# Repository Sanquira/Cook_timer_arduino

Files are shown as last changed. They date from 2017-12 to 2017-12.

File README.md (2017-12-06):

# Cook_timer_arduino

Project of Cooking timer based on Arduino Nano ATmega328.

Project is designed with focus on modularity. Therefore there are few independent modules:

Event       - Simple event template. Used for firing events like button pressed, buzzer melody ended (or was ended),
              timer timed out.

Button      - Module which allows you to register button on pin with debounce feature and event response in program.

Buzzer      - Module for sound output with support of melody and/or cycle play.

TimerLogic  - Module for time measure designed on minutes scale. Fire event when timer ends.
              Inner timer count in millis. There is support for "live" add/remove time.
              It will return you remaining time in minutes and in seconds and second ticking indicator.
              Timer reset itself when stopped.

LedDisp     - Module for 4 digits 7-segments LED display. It uses multiplex technology so it needs 8 + 4 pins when registering.

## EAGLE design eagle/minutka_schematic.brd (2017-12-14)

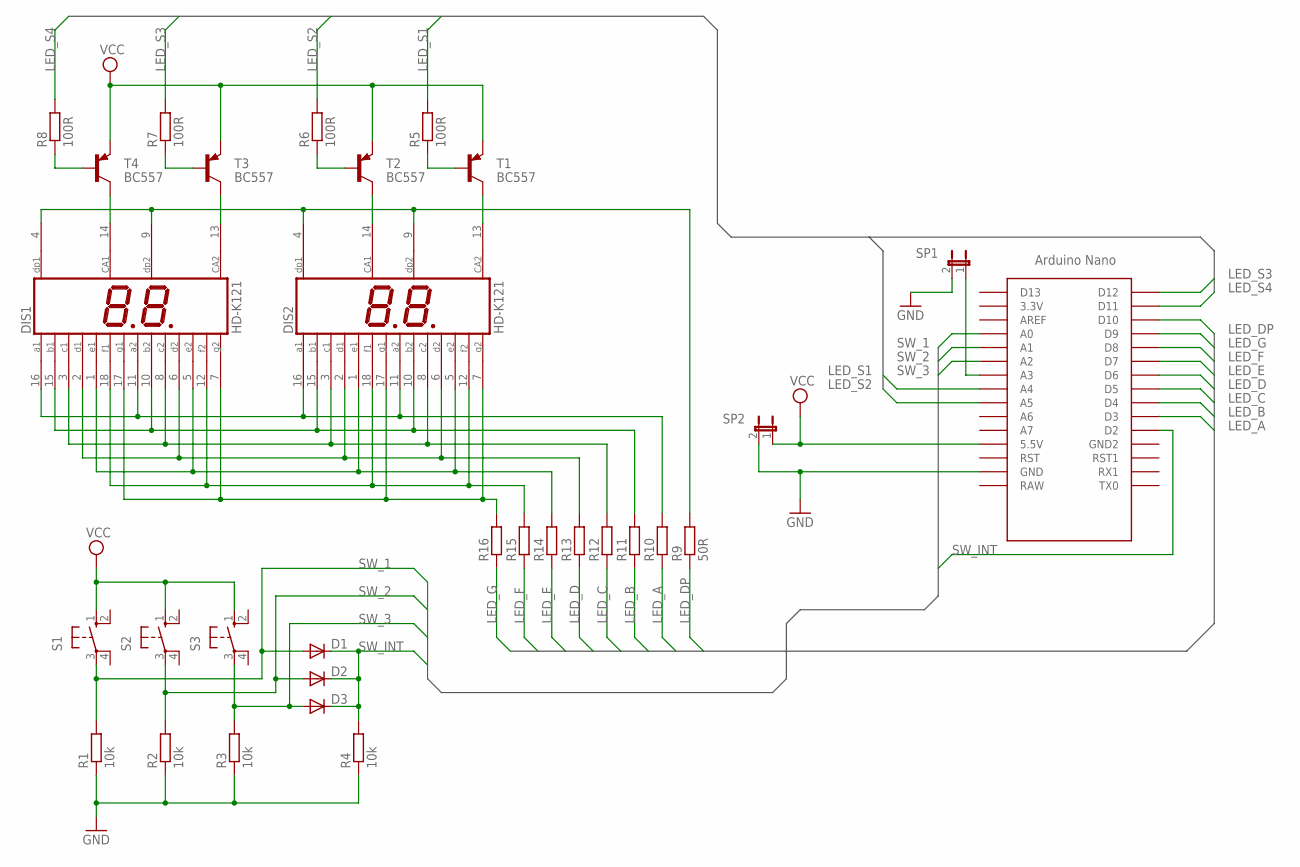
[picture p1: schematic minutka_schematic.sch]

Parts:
D1, D2, D3: DIODE-D-5; D-5
DIS1, DIS2: HD-K121; HDSP-R
R1, R2, R3, R4: 10k; 0204/7
R5, R6, R7, R8: 100R; 0204/7
R9: 50R; 0204/7
R10, R11, R12, R13, R14, R15, R16: R-EU_0204/7; 0204/7
S1, S2, S3: 10-XX; B3F-10XX
SP1, SP2: JP1E; JP1
T1, T2, T3, T4: BC557; TO92-EBC
U$1: NANO

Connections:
GND: R1.1, R2.1, R3.1, R4.1, SP1.2, SP2.2, U$1.GND
LED_A: R10.1, U$1.D3
LED_B: R11.1, U$1.D4
LED_C: R12.1, U$1.D5
LED_D: R13.1, U$1.D6
LED_DP: R9.1, U$1.D10
LED_E: R14.1, U$1.D7
LED_F: R15.1, U$1.D8
LED_G: R16.1, U$1.D9
LED_S1: R5.2, U$1.A4
LED_S2: R6.2, U$1.A5
LED_S3: R7.2, U$1.D12
LED_S4: R8.2, U$1.D11
unnamed: DIS1.11 (A2), DIS1.16 (A1), DIS2.11 (A2), DIS2.16 (A1), R10.2
unnamed: DIS1.10 (B2), DIS1.15 (B1), DIS2.10 (B2), DIS2.15 (B1), R11.2
unnamed: DIS1.3 (C1), DIS1.8 (C2), DIS2.3 (C1), DIS2.8 (C2), R12.2
unnamed: DIS1.2 (D1), DIS1.6 (D2), DIS2.2 (D1), DIS2.6 (D2), R13.2
unnamed: DIS1.1 (E1), DIS1.5 (E2), DIS2.1 (E1), DIS2.5 (E2), R14.2
unnamed: DIS1.12 (F2), DIS1.18 (F1), DIS2.12 (F2), DIS2.18 (F1), R15.2
unnamed: DIS1.7 (G2), DIS1.17 (G1), DIS2.7 (G2), DIS2.17 (G1), R16.2
unnamed: DIS1.4 (DP1), DIS1.9 (DP2), DIS2.4 (DP1), DIS2.9 (DP2), R9.2
unnamed: DIS2.13 (CA2), T1.C
unnamed: DIS2.14 (CA1), T2.C
unnamed: DIS1.13 (CA2), T3.C
unnamed: DIS1.14 (CA1), T4.C
unnamed: R7.1, T3.B
unnamed: R8.1, T4.B
unnamed: R6.1, T2.B
unnamed: R5.1, T1.B
unnamed: SP1.1, U$1.A3
SW_1: D1.A, R1.2, S1.3, U$1.A0
SW_2: D2.A, R2.2, S2.3, U$1.A1
SW_3: D3.A, R3.2, S3.3, U$1.A2
SW_INT: D1.C, D2.C, D3.C, R4.2, U$1.D2
VCC: S1.1 (S), S2.1 (S), S3.1 (S), SP2.1, T1.E, T2.E, T3.E, T4.E, U$1.5V (5.5V)

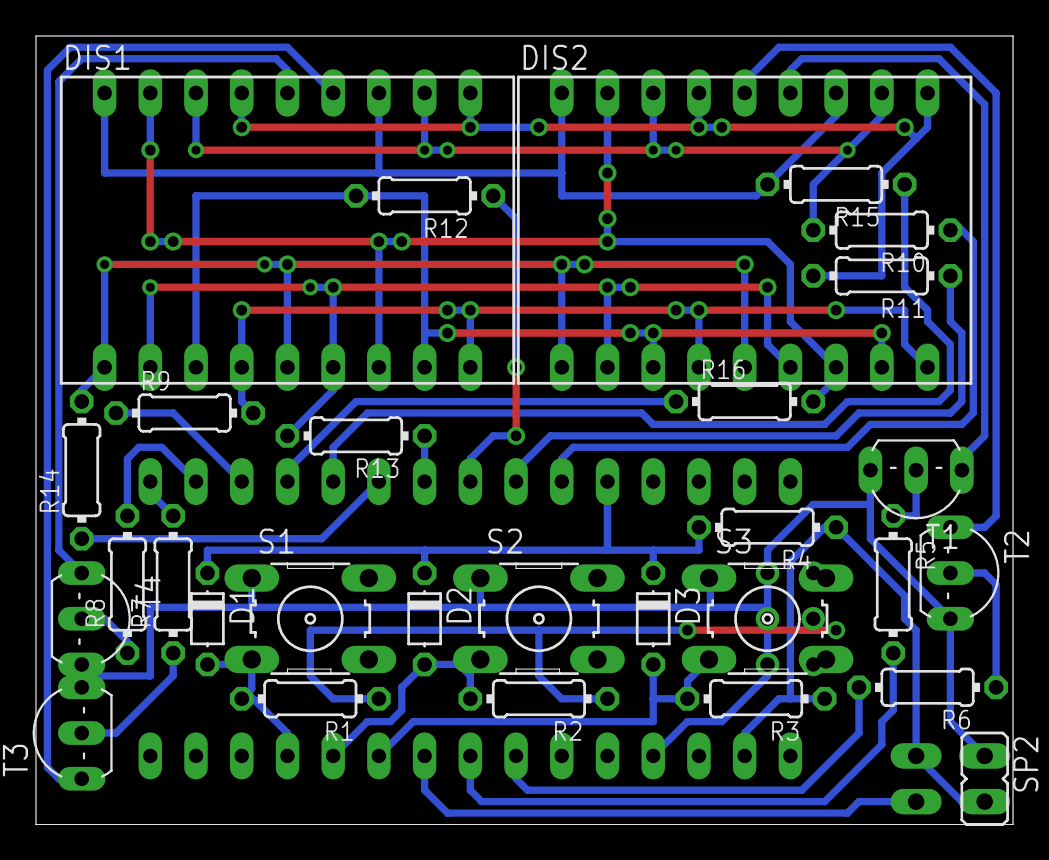
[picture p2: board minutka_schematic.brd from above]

Board: 2 copper layers, 54.3 x 43.8 mm, 31 parts (1 on the bottom side), 35 nets.

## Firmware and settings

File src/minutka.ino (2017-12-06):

#include "LedDisp.h"
#include "Button.h"
#include "TimerLogic.h"
#include "Buzzer.h"
#include <avr/sleep.h>

void wakeUpNow();

bool m_isWakingUp;
LedDisp led;
Buzzer buzzer = Buzzer(4);
TimerLogic timer;
TimerLogic sleepTimer;
class timers {
  public:
    void timers::init() {
      timer.setTimeoutEvent(new EventHandler<timers, TimeoutEventArgs>(this, &timers::onTimeout));
      sleepTimer.setTimeoutEvent(new EventHandler<timers, TimeoutEventArgs>(this, &timers::onSleepTimeout));
      sleepTimer.setDesiredTime(10000);
    }

    void timers::onTimeout(TimeoutEventArgs* args) {
      buzzer.startBuzzer();
      sleepTimer.stopTimer();
    }

    void timers::onSleepTimeout(TimeoutEventArgs* args) {
      led.setEnabled(false);
      sleep_enable();
      attachInterrupt(digitalPinToInterrupt(2), wakeUpNow, HIGH);
      sleep_mode();
      // THE PROGRAM CONTINUES FROM HERE AFTER WAKING UP
      sleep_disable();
      detachInterrupt(digitalPinToInterrupt(2));
      led.setEnabled(true);
    }

    void timers::onStupidTimeout(TimeoutEventArgs* args) {
      timer.startTimer();
      sleepTimer.stopTimer();
    }

    void timers::process(unsigned long currentMillis) {
      timer.process(currentMillis);
      sleepTimer.process(currentMillis);
    }

} timers;
class Buttons {
  public:
    Button startButton, plusButton, minusButton;

    void Buttons::init() {
      plusButton.registerButton(A0, new EventHandler<Buttons, ButtonEventArgs>(this, &Buttons::onPlusPressed));
      startButton.registerButton(A2, new EventHandler<Buttons, ButtonEventArgs>(this, &Buttons::onStartPressed));
      minusButton.registerButton(A1, new EventHandler<Buttons, ButtonEventArgs>(this, &Buttons::onMinusPressed));
    }

    void Buttons::onPlusPressed(ButtonEventArgs* args) {
      if (m_isWakingUp) {
        m_isWakingUp = false;
        sleepTimer.resetTimer();
        return;
      }
      timer.increaseTime();
      if (!timer.isRunning())
        sleepTimer.resetTimer();
    }

    void Buttons::onMinusPressed(ButtonEventArgs* args) {
      if (m_isWakingUp) {
        m_isWakingUp = false;
        sleepTimer.resetTimer();
        return;
      }
      timer.decreaseTime();
      if (!timer.isRunning())
        sleepTimer.resetTimer();
    }

    void Buttons::onStartPressed(ButtonEventArgs* args) {
      if (m_isWakingUp) {
        m_isWakingUp = false;
        sleepTimer.resetTimer();
        return;
      }
      if (buzzer.isRunning()) {
        buzzer.stopBuzzer();
        sleepTimer.resetTimer();
        return;
      }
      if (timer.isRunning()) {
        timer.stopTimer();
        sleepTimer.resetTimer();
      }
      else {
        timer.startTimer();
        sleepTimer.stopTimer();
      }
    }

    void process(unsigned long currentMillis) {
      plusButton.process(currentMillis);
      startButton.process(currentMillis);
      minusButton.process(currentMillis);
    }

} buttons;
class Buzzers {
  public:
    void Buzzers::init() {
      buzzer.registerBuzzer(A3, new EventHandler<Buzzers, BuzzerEventArgs>(this, &Buzzers::onEnded), true);
      // fur elise 20
      //      buzzer.addTone(NOTE_E6, 250);
      //      buzzer.addTone(NOTE_DS6, 250);
      //      buzzer.addTone(NOTE_E6, 250);
      //      buzzer.addTone(NOTE_DS6, 250);
      //      buzzer.addTone(NOTE_E6, 250);
      //      buzzer.addTone(NOTE_B5, 250);
      //      buzzer.addTone(NOTE_D6, 250);
      //      buzzer.addTone(NOTE_C6, 250);
      //      buzzer.addTone(NOTE_A5, 250);
      //      buzzer.addTone(0, 50);
      //      buzzer.addTone(NOTE_C5, 250);
      //      buzzer.addTone(NOTE_E5, 250);
      //      buzzer.addTone(NOTE_A5, 250);
      //      buzzer.addTone(NOTE_B5, 250);
      //      buzzer.addTone(0, 50);
      //      buzzer.addTone(NOTE_E5, 250);
      //      buzzer.addTone(NOTE_GS5, 250);
      //      buzzer.addTone(NOTE_B5, 250);
      //      buzzer.addTone(NOTE_C6, 250);
      //      buzzer.addTone(0, 50);
      // annoying 4
      buzzer.addTone(1600, 500);
      buzzer.addTone(1500, 500);
      buzzer.addTone(1400, 500);
      buzzer.addTone(1500, 500);
    }

    void Buzzers::onEnded(BuzzerEventArgs* args) {
      sleepTimer.resetTimer();
      led.dispDP2(1);
    }
} buzzers;

void setup() {
  int arr[] = {3, 4, 5, 6, 7, 8, 9, 10};
  led.init(arr, 11, 12, A5, A4);
  buttons.init();
  timers.init();
  buzzers.init();

  led.dispDP2(1);

  set_sleep_mode(SLEEP_MODE_PWR_DOWN);
  m_isWakingUp = false;
  sleepTimer.startTimer();
}

void loop() {
  unsigned long currentMillis = millis();
  timers.process(currentMillis);
  led.dispNumber(timer.getDisplayTimeMinutes(), timer.getDisplayTimeSeconds());
  led.dispDP2(timer.getSecondMark());
  led.draw(currentMillis);
  buttons.process(currentMillis);
  buzzer.process(currentMillis);
}

void wakeUpNow()
{
  m_isWakingUp = true;
  // execute code here after wake-up before returning to the loop() function
  // timers and code using timers (serial.print and more...) will not work here.
}

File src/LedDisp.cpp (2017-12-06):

#include "LedDisp.h"

LedDisp::LedDisp() {}

LedDisp::~LedDisp() {
  delete [] arr;
}

void LedDisp::init(int segmsLed[8], int minuteD, int minuteU, int secondD, int secondU) {
  for (int i = 0; i < 8; i++) {
    arr[i] = segmsLed[i];
  }
  drawPins[0] = minuteD;
  drawPins[1] = minuteU;
  drawPins[2] = secondD;
  drawPins[3] = secondU;

  currentDraw = 0;
  for (int i = 0; i < 8; i++) {
    pinMode(arr[i], OUTPUT);
    pinMode(arr[i], LED_RST);
  }
  for (int i = 0; i < 4; i++) {
    pinMode(drawPins[i], OUTPUT);
  }
  enableDigits(false);
  setEnabled(true);
}

void LedDisp::draw(unsigned long currentMillis) {
  if (!m_enabled)return;
  if (currentMillis - previousDraw_ms >= DRAW_INTERVAL) {
    previousDraw_ms = currentMillis;

    setDisp(currentDisp[currentDraw], drawPins[currentDraw]);
    currentDraw = (currentDraw + 1) % 4;
  }
}

void LedDisp::dispDP(int index, int value) {
  if (index < 0 || index >= 4) return;
  currentDisp[index] = currentDisp[index] ^ ((-value ^ currentDisp[index]) & (1 << 7));
}

void LedDisp::dispDP1(int value) {
  currentDisp[0] = currentDisp[0] ^ ((-value ^ currentDisp[0]) & (1 << 7));
}

void LedDisp::dispDP2(int value) {
  currentDisp[1] = currentDisp[1] ^ ((-value ^ currentDisp[1]) & (1 << 7));
}

void LedDisp::dispDP3(int value) {
  currentDisp[2] = currentDisp[2] ^ ((-value ^ currentDisp[2]) & (1 << 7));
}

void LedDisp::dispDP4(int value) {
  currentDisp[3] = currentDisp[3] ^ ((-value ^ currentDisp[3]) & (1 << 7));
}

void LedDisp::dispNumber(int minuteNumber, int secondNumber) {
  //minutes
  if (minuteNumber > 99)
  {
    currentDisp[0] = ERR;
    currentDisp[1] = ERR;
  } else  if (minuteNumber < 10) {
    currentDisp[0] = NONE;
    currentDisp[1] = decodeNumber(minuteNumber);
  }  else {
    int decimal = minuteNumber / 10;
    int unimal = minuteNumber - (decimal * 10);
    currentDisp[0] = decodeNumber(decimal);
    currentDisp[1] = decodeNumber(unimal);
  }

  //seconds
  if (secondNumber > 99)
  {
    currentDisp[2] = ERR;
    currentDisp[3] = ERR;
  } else {
    int decimalS = secondNumber / 10;
    int unimalS = secondNumber - (decimalS * 10);
    currentDisp[2] = decodeNumber(decimalS);
    currentDisp[3] = decodeNumber(unimalS);
  }
}

void LedDisp::setDisp(char value, int digit) {
  char mask = 0x00000001;
  enableDigits(false);
  for (int i = 0; i < 8; i++) {
    if ((mask & (value >> i)) == 1)
      digitalWrite(arr[i], LED_ENA);
    else
      digitalWrite(arr[i], LED_RST);
  }
  digitalWrite(digit, DIGIT_ENA);
}

void LedDisp::enableDigits(bool ena) {
  if (ena) {
    for (int i = 0; i < 4; i++) {
      digitalWrite(drawPins[i], DIGIT_ENA);
    }
  } else {
    for (int i = 0; i < 4; i++) {
      digitalWrite(drawPins[i], DIGIT_RST);
    }
  }
}

char LedDisp::decodeNumber(int number) {
  switch (number) {
    case 0:
      return ZERO;
    case 1:
      return ONE;
    case 2:
      return TWO;
    case 3:
      return THREE;
    case 4:
      return FOUR;
    case 5:
      return FIVE;
    case 6:
      return SIX;
    case 7:
      return SEVEN;
    case 8:
      return EIGHT;
    case 9:
      return NINE;
    default:
      return NONE;
  }
}

bool LedDisp::isEnabled() {
  return m_enabled;
}
void LedDisp::setEnabled(bool value) {
  m_enabled = value;
  enableDigits(m_enabled);
}

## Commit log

2017-12-06 Finished project of "cooking timer".
2017-12-14 Added eagle schematic and board.
    Renamed project code folder
    [minutka_schematic.brd, minutka_schematic.sch]
